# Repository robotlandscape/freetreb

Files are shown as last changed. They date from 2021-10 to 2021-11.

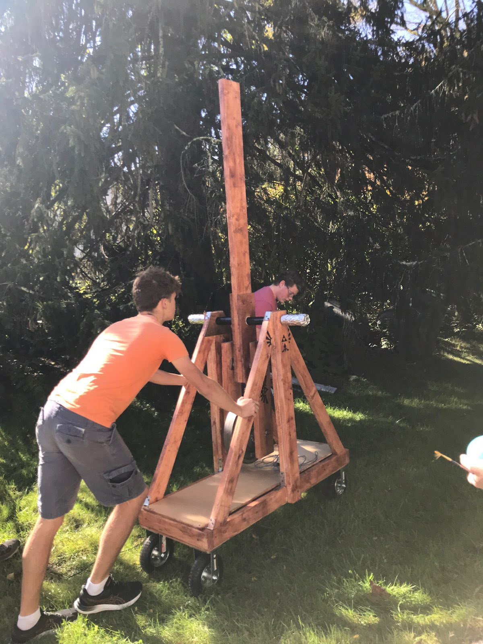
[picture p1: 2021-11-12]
projects/2021 Ganon Cannon/Gallery/IMG_1636.jpg

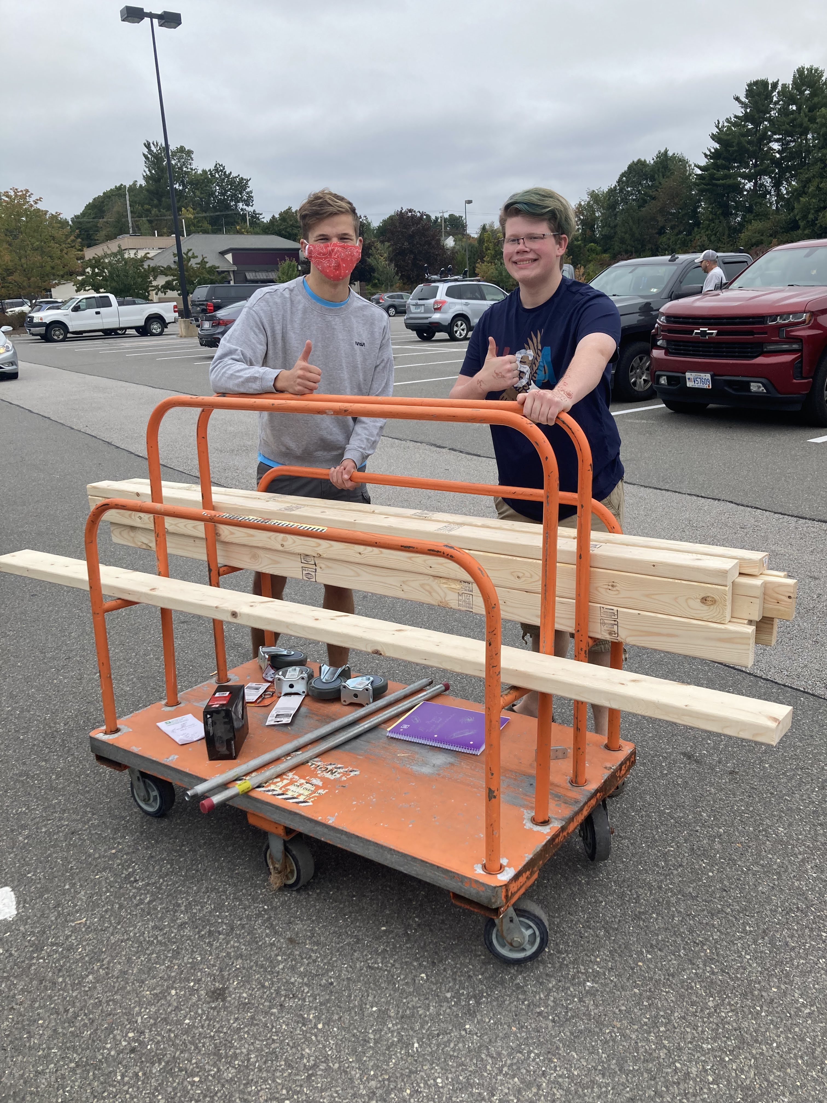
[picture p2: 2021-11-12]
projects/2021 Ganon Cannon/Gallery/At home depot.jpg

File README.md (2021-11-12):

# Freetreb: Open Source Trebuchet Documentation

> It ain't cheating if it's allowed!

Are you building a trebuchet for your WHS Physics assignment? 

Do you have no idea how to build a trebuchet, hopelessly looking at designs online built by people just as frantic as you are? 

Is it October 25th and your trebuchet is still firing backwards? 

Are you thinking about sinking so low as to go to the Windham black market for trebuchets? 

*All of the above?*

### Look no further! 

This is a repository of fellow sleep-deprived trebuchet-builders to record and document what worked for them, what didn't, how they fixed problems, and what their final result was. Because trebuchet day is an assignment and not necessarily a competition, collaboration benefits everyone who contributes! 

So what we have to offer you is a repository of open source trebuchet designs, an in-depth showcase of what works, what worksn't, and how to build your own water balloon-launching instrument of carnage. 

## Before you continue...

My only condition for using this free resource is that you contribute back. If you find the information that I (and eventually others) have put here, then to have it be a fair trade, *please* put your own treb here. The Honor System applies. Don't cheat, don't take anyone's work verbatim. 

Mr. Kaplo is alright if you do your journal-work here instead of/in addition to your actual journal. 

If you have trouble using github itself, then take a look at the file CONTRIBUTING.md, it should tell you enough to get started on adding your treb here :D

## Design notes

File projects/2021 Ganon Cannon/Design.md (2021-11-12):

# Design

> Each journal must contain... a written discussion of your major design considerations. Specifically, placement of the main axle on the throwing arm, throwing arm material and geometry, structural integrity, counterweight type, and sling fabrication and design. Modifications to design, experimentation and trials should also be discussed here.

Many of our design considerations were based on research we did online before starting the project. We looked into several types of trebuchets, and almost did a whipper trebuchet, but opted for a normal one on the basis that it was better documented online. 

### Ratios

The main axle of our throwing arm was put at a ratio of 3.75:1, with 3.75 being the length of the throwing arm side of the main arm, and 1 being the side with the counterweight. 

### Materials

We opted to use maple 2 by 4's for most of the project, however we actually decided to get a single 2 by 6 for the throwing arm because we had heard a lot of 
stories from past years of throwing arms snapping. Therefore, we got a thicker plank of wood for that particular piece. 

### Structure

Structural integrity was something we took somewhat for granted, but we knew generally what we wanted. Each trestle was supported by triangles along the throwing axis. **However one thing I would do differently if I were to do this project again would be to have the supporting trestles inside the base**, because that way the base would almost act as a "pen" for the trestles to live in, versus what we have which is the trestles on top of the base, just screwed on. 

### Wheels

We added wheels to our trebuchet. This is one of the most distinctive part of our design, as out of the 57 teams that participated this year, I only observed 3 teams, including us, with wheels on our trebuchet. The rationale behind this decision was that the potential energy of the weight is better utilized when the weight drops *straight down*. (source: https://www.youtube.com/watch?v=-gn2RGPqe_A) In hindsight it would have been just as effective to calculate the proper length that the counterweight arm would need to be, but we didn't do this. 

### Counterweight

The counterweight is 150 lbs of lifting weights. If I were to do this project again I'd have a system to modify the weight better, I saw some people with a basket that they put their weight in, which, although it didn't look as nice as ours, we didn't have as much flexibility to change them out as much (it was quite an ordeal to get the first ones on).

Our rationale for how long to make the counterweight arm was mostly based on what would fit without hitting the sliding board, but we accounted for the otherwise worse efficiency with wheels (see above)

### Sling

The sling was made quite nicely out of some crocodile leather that my partner had lying around. We made it into an X shape, sowed it together, sowed each of the two arms together almost like an infinity sign, and added gromets to each end. We also added a piece of gorilla tape to the bottom of the sling (the side that dragged on the sliding board) to fix it releasing too early/late. 

#### Sling hook

The release hook (where the sling released the balloon was just a nail. We were going to do something fancy but ran out of time. Do a nail, it works fantastically and you can modify the release angle with a pair of pliers. 

### Safety/Release pin

To release our trebuchet and hold it tight, we had an I-hook system on the throwing arm and two on the base of the treb. A pin went through all three and stayed there until we wanted to release, at which point we would pull horizontally and it would release. See the CAD design for a visual.

### Beautification

As far as aesthetics goes, we gave the boring pale wood a nice varnish, added some Legend of Zelda symbolism to go with our theme, and painted our sliding board black. It looked quite nice!

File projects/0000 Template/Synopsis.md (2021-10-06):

### Introduce yourselves! What's your group, who's in it, what theme are you going for?

### What materials are you using? Any Recycled Materials? What about the counterweight?

### What's the plan? What are you going to do for your trebuchet? Is there anything about it that hasn't been done before? (if not, try something!)

### Are there any other resources you're using other than this repository?

### Anything else that you'd like to share that wasn't asked above?

### How'd it go? 
*for after treb day*

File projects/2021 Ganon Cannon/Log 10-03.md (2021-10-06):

First log in the repository! (besides the template one). Granted, I'm writing this 3 days after this all happened, but that's fine. 

I went to my partner's house at 10, and we pretty much went straight to home depot to get the majority of the materials we thought we would need, 
which was 10 2-by-4s (and a 2-by-6 for the throwing arm, we thought it would be better if it was thicker for strength). We also bought 10 angle brackets
(we wound up being 2 short, as we found out later) and four wheels. 

We went to work, we built a rectangular frame for the bottom (dimensions will be a separate file), then two vertical pillars on either side. We reinforced this
with diagonal 2-by-4s (on the last one was when we realized we were short 2 angle brackets so we went back to home depot for those). The vertical pillars were a
little crooked so we spent the rest of the time fixing those, then we called it a day.

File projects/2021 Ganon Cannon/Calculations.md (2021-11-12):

***Reminder on the honor system: Please do your own work here. If you need to, feel free to use this as a reference, but do your own work and make sure you understand it.***

> Calculations including: 
> - X and Y components of velocity, 
> - initial velocity vector shown graphically (as the sum of the components) and calculated analytically, 
> - and maximum height. 
> 
> You will be supplied with the time of flight and range of your projectile.

I'll work in terms of variables for now, then substitute my values in afterwards. 

```
d = distance
t = time of flight
h = release height, sqrt(1.3815^2 + 1.3815^2) + 1.2553 = 3.111 for our particular trebuchet
g = -9.81
                                        # when I do this it means I'm explaining a line
------------------------

v_x = d/t                               # Speed is distance over time

v_y:
x = x_i + v_i t + atˆ2/2                # Position formula
a is g
x is 0
x_i is h
x_f - atˆ2/2 = x_i + v_i t 
x_f - atˆ2/2 - x_i = v_i t 

v_y = (0 - (gtˆ2/2) - h)/t                  # rearrange for v_i

-------------------------

velocity vector: 
direction/angle: atan(v_y/v_x)                   # aTan gives the angle from a slope
magnitude: sqrt(v_y^2 + v_x^2)                  # Pythagoras :D

-------------------------

Maximum height: 
v = v_i + at
0 = v_y + gt                                    # We're kinda looking for the time at which the velocity is 0, so let's set v = 0
(v_y)/(g) = t                                   # rearrange for t
x = x_i + v_i t + atˆ2/2                        # now plug that into t in the position equation
x = x_i + v_i (v_y)/(g) + a((v_y)/(g))ˆ2/2      # woah that's long
h_max = h + v_y^2/g + g((v_y)/(g))ˆ2/2          # simplified a bit

~~~~~~~~~~~~~~~~~~~~~~~~~~~~~~~~~~~~~~~~~~~~~~~~~~

Launch 1:
d = 32 m
t = 2.6 s

v_x = d/t
= 12.307 m/s
= 44.28 mph!

v_y = (0 - (gtˆ2/2) - h)/t
= 11.556 m/s
= 41.6 mph

v = sqrt(v_y^2 + v_x^2)
= 16.882 m/s
= 60.7 mph! 

Θ = atan(v_y/v_x)
= 0.753 rad
= 43.19 degrees                                 # if only I had done this before, I would have changed the release angle a bit

max height: 
h_max = h - v_y^2/g + g((-v_y)/(g))ˆ2/2
= 24.116 m

(Only doing the first launch because the second launch was a misfire and the person recording didn't record the time for the third launch.)
```

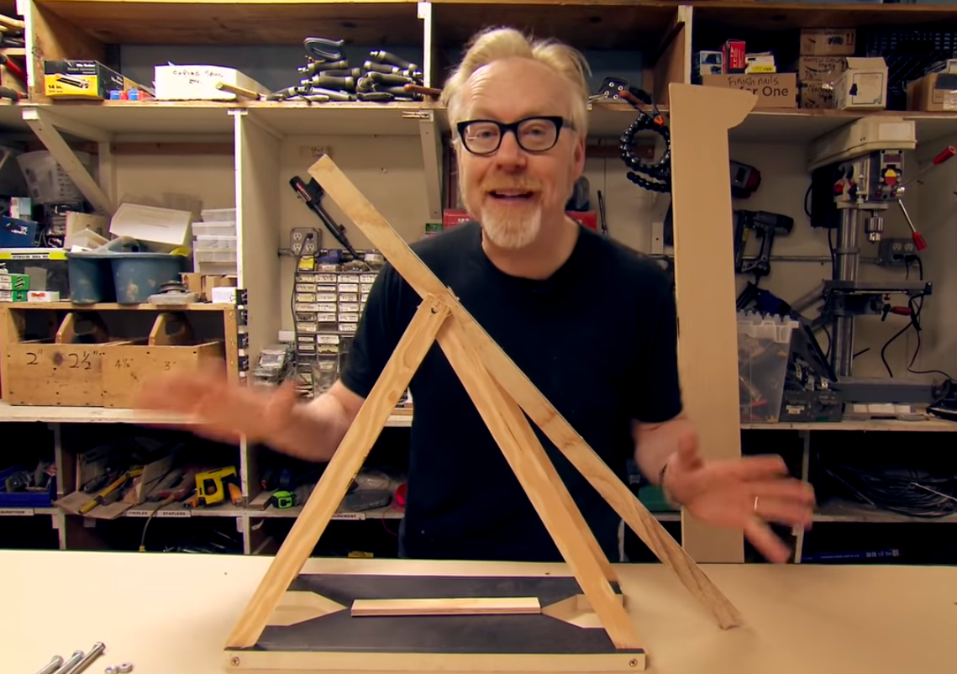
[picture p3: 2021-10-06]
projects/0000 Template/Me with my treb.png

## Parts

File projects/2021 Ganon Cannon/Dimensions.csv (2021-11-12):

Dimension | value | units | notes
Throwing arm | 1.75 | meters
Base Length | 1.3125 | meters
Base Width | 0.4370 | meters
Trestle Height | 0.98 | meters
Throwing arm ratio | 3.75:1
Throwing side of throwing arm | 1.3815 | meters
Counterweight side of throwing arm | 0.3684 | meters
Sling Length | 1.3815 | meters | same as throwing arm side length
Standard Water Baloon | 500 | Milliliters | also 18 OZ
Counterweight weight | 68.03 | Kilograms | also 150 lbs
Counterweight arm length | 0.689 | meters
Wood Type | Maple
Wood density | 700 | kg per cubic meter | based on https://matmatch.com/learn/property/density-of-wood

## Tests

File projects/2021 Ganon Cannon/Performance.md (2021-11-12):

# Pre-First shot

Before we even arrived we came acknowledging that our trebuchet was in a sub-optimal place, but we decided to go with it anyway, thinking correctly that the 
majority of our tweaking would be better to do on-site. 

Day of, my partner and I set up the treb in the correct position. Super cold. First period comes and I go with a bunch of other students to help set up the castle. 

# First official shot

We were the first person to fire a water baloon :D We were ready and we wanted to be the first. It went into the B area. 

Many of our shots went like that, after a while we got into a system. However many of our shots were misfiring or going straight up. We didn't have a solution, 
we did have potential sources of the problem though, including the wheels, the release angle, and the sling. 

It was cold, we were kinda unhappy with where our treb was, and it wasn't all that great, but somehow our treb hit the exterior wall of the castle, and we were 
the first to get an A :D

# Second official shot

We still didn't have a solution to the firing-straight-up problem, but since the pressure was off from our first shot, we didn't worry too much about it, and we 
didn't try to solve it. We did a lot of practice shots though, and it was a bit embarrasing in hindsight because every other shot we'd have to shout "HEADS UP!"

We did, however, get into a system of getting it to misfire the least, a certain string arrangement. This didn't stop us from being the first to get a D in the
second shot with another misfire. (Being one of the lowest team numbers helps with all these "firsts")

# Third official shot

Dan from team #1 came to us shortly after this misfire and suggested that it could be a sling issue, and so we went to another team (I forget which one) and 
borrowed some gorilla tape that they had brought, and applied it to the bottom of our sling, the side that faced the sliding board (the black board in the CAD). 
I think that it was that the sling was releasing too early, or that sometimes the balloon would be in contact with the sliding board and pop there and then, or 
sometimes the balloon would wedge itself in the gap that we covered with the tape, to not release at all. 

After our fix, the balloon made it consistently into the castle, with the biggest variations coming from the wind. Unfortunately on our official shot, we did have
the wind working against us, so we got a B on the last shot. Given another shot I'm pretty sure we could have hit Mr. Kaplo, but I'm happy with how we did overall,
even if our *best* shot was a fluke.

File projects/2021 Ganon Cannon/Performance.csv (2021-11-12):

Group Info |  |  |  |  | Safety Check |  | Costume Bonus |  | Official Throw #1 |  |  |  |  |  |  | Official Throw #2 |  |  |  |  |  |  | Official Throw #3 |  |  |  |  |  |  | FINAL
# | Last Name | First Name | P | Team Name | Pass | Notes | Score (0-5) | Notes | Distance (m) | Time (s) | Castle exterior hit | Castle interior hit | Teacher hit bonus | Grade | Score | Distance (m) | Time (s) | Castle exterior hit | Castle interior hit | Teacher hit bonus | Grade | Score | Distance (m) | Time (s) | Castle exterior hit | Castle interior hit | Teacher hit bonus | Grade | Score | Best | Final Score
4 | Lincoln | Connor | TRUE | Ganon Cannon | TRUE |  | 5 |  | 32 | 2.6 | TRUE | FALSE | FALSE | A | 47/50 | 0 | 0 | FALSE | FALSE | FALSE | D | 34/50 | 31 |  | FALSE | FALSE |  | B | 43/50 | 47
 | Diesel | Torsten | TRUE

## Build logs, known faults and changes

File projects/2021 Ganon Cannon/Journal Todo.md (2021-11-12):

 - [x] Finish CAD of Trebuchet
 - [ ] "Calculations including: X and Y components of velocity, initial velocity vector shown graphically (as the sum of the components) and calculated analytically, and maximum height. You will be supplied with the time of flight and range of your projectile."
 - [x] A written discussion of your major design considerations.  Specifically, placement of the main axle on the throwing arm, throwing arm material and geometry, structural integrity, counterweight type, and sling fabrication and design.  Modifications to design, experimentation and trials should also be discussed here. 
 - [ ] A couple pictures. 
   - [ ] If I have enough time: a 5-10 minute documentary video of the build process :D

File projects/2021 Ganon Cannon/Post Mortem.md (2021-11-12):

# Post-mortem

This isn't anything that is required of the journal, these are a compilation of things we would have done differently if we had the chance. 

- The trestles could have been *inside* of the base, this would have probably made it sturdier. We didn't have any stability issues, but this would have made it stronger. 
- I think we drilled the holes for the counterweight arm too close to the axis on the swinging arm. I can't verify this as I don't have the trebuchet, but this probably made our ratio different, and our trebuchet less efficient. 
- I would have liked to have documented what we did better while we were doing it, but I get why I didn't (too in-the-moment). 
- I'm not going to have time to do the video, it would have been nice to have done that. 
- We should have had a better system for changing out the weights. 
- I think we should have maybe done a bit more research on sling designs. Ours worked fine in the end but not without modification.

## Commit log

2021-11-11 Removed all but our row
    [Treb Day Performance.csv]
2021-11-11 Removed redundant column
    The 2nd column, P, was originally intended to be whether or not the permission slip was given, but Mr. Kaplo wound up using something else for that, so the information there is irrelevant and inaccurate.
    [Treb Day Performance.csv]
2021-11-11 Added some values and changed to csv
    [Dimensions.csv]
2021-11-11 added comma to line 12
    [Dimensions.csv]
2021-11-11 Add CAD design
    [CAD.stl]
2021-11-12 Rename Treb Day Performance.csv to Performance.csv
    [Performance.csv]
2021-11-12 Renamed some stuff
    [Dimensions.csv, Performance.csv]
